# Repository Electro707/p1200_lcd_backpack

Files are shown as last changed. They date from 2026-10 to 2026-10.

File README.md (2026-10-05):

# P1200 - LCB Backpack
# WIP

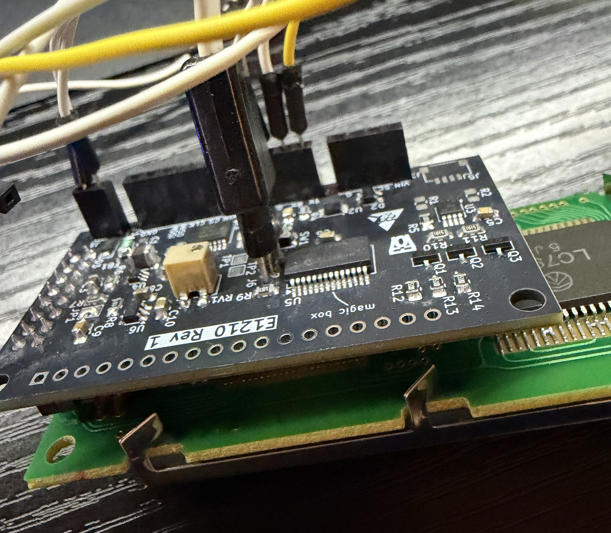
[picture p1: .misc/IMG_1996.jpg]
Image of board on an LCD during development

*Image of board on an LCD during development*

This project is for a generic LCD backpack, similar to the many ones out there, with some distinct features that lead me to build my own:

- Negative voltage for the LCD Bias
    - This was the biggest reason I made this project, as I had an older LCD that wouldn't work unless the LCD is biased to -2v. This is OK as most LCDs can be biased to -9v below VCC, I think?
- Both 5v and 3.3v power and data compatibility
- UART, SPI, and I2C protocols
- The ability to offload some functionality to this backpack, such as animations on the LCD

# Project Structure:

- E1201: The KiCAD PCB files
- F1202: The firmware folder
- Release: All locked in files

# PCB Jumper and Notes

TODO: this section

# PCB Errata
The ERRATA's for the latest revision PCB can be found in [`ERRATA.md`](ERRATA.md)

# Firmware
The [firmware for this project](F1202/) is targeted towards the MCU on board (PIC16F18155).

To use the project, open it up in MPLAB IDE (v6.35 used), with PIC-AS 4.00 (comes with XC8) and device pack `PIC16F1xxxx_DFP==1.31.465` (other version should be OK, noted for repeatability).

The project is written in assembly.
Why? Why not?
This was mostly for my learning of writing an entire firmware in bare assembly and getting familiar with the PIC architecture. I found it fun.

More info on the firmware, including the communication protocol, can be found in [F1202/README.md](F1202/README.md)

# License
This project is licensed under [GPLv3](LICENSE.md)**

** This excludes the files in `E1201/SparkFun-Qwiic.pretty`, as they [came from the Sparkfun](https://www.sparkfun.com/qwiic)

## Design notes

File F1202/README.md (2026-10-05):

# F1202 Detailed Document

This firmware is designed to run on a PIC16F18154 on a E1201 PCBA

## UART Protocol

This firmware speaks over 19200 8N1 serial.

This uses an escape frame sequence, with the escape key (0x1B) serving as the escape code.

Responses are ACK (0x06) for successful command execution, or NACK (0x15) for invalid commands or arguments

The fist byte is the command, which the following are available. Anything with a {N} means it's not implemented yet
- {N}0x01: Get firmware name
- 0x1x: LCD direct commands
    - 0x10: Clear and home
    - 0x11: Go home
    - {N}0x12: Set DRAM position
        - 1 byte argument
    - 0x13: Write to display
        - N byte, continuous
        - An ACK is sent every byte, and directly updates the LCD
    - {N}0x1A: Set CGRAM address
        - 1 byte
    - {N}0x1B: Set CGRAM data
        - 5 bytes
- {N}0x2x: Backlight commands
    - 0x20: Turn off backlight
    - 0x21: Turn on regular backlight
    - 0x22: Turn on RGB backlight
    - 0x23: Set regular (R) backlight PWM
        - 1 byte argument
    - 0x24: Set G backlight PWM
        - 1 byte argument
    - 0x25: Set B backlight PWM
        - 1 byte argument

## SPI Protocol

TODO

## I2C Protocol

TODO

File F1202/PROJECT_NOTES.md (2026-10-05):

# F1202 Notes

> These are notes I wrote down when developing the firmware. Some of them may be handy, some not ¯\_(ツ)_/¯

Each cycle in our system is 250nS (16 Mhz / 4)

according to hd444780:
- the data setup time 80nS, so 1 cycle is ok.
- PWEH is 230nS, so best to have another NOP if we are running back-to-back commands with no data change, but shouldn't be needed
- Setup time is 60nS, so more than enough for 1 cycle

We are using the busy pin, so that is the waiting mechanism in our system.

When writing data, there is a 4uS delay on top of the BUSY pin going LOW due to tADD, so that has to be done manually. Would result in 16 NOPs.

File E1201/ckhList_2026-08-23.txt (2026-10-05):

Unknown List

Schematic Part#: E1201 Rev 1
PCB Part#: 
Reviewers: JB
Date: 2026-08-23
Notes:

Schematic, Generic: 
- [ X ] Run ERC, ensure all errors are accounted for (s1)
- [ X ] Ensure title block is somewhat correct (s2)
- [ X ] Ensure a nominal passive voltage/power/tolerances spec are listed (s3)
- [N/A] Check that all passives with non-nominal rating (especially capacitor voltage) is explicitly called out (s4)
- [ X ] Check pinout of any previously unused symbol against datasheet (s5)
- [ X ] Ensure footprint of symbols are set to maximal pad size if pcb space allows for hand-solderability (s6)
- [ X ] Inverted signals should be indicated (bar on top or _N suffix) (s7)

Schematic, Digital: 
- [ X ] Check that a microcontroller's pin functions is allowed on that pin, either fixed function per pin or an internal mux (sdig1)
        > mcu has pps, check all IO ports required can be connected
- [ X ] Double check I2C and SPI connections (SDA vs SCL for example) (sdig2)
- [ X ] Triple check UART directionality, or add poka-yoke (sdig3)

PCB, Generic: 
- [ X ] Check design rule check matches manufacturer tolerances, if different than default (p1)
- [ X ] Run DRC, ensure no unexpected errors (p2)
- [ X ] Ensure copper pours have no neck-downs (p3)
- [ X ] Ensure copper pours are tied to a net (p4)
- [ X ] Check footprint (especially self-made) of any previously unused footprint against datasheet (p5)

PCB, Silkscreen: 
- [ X ] Check that reference designators are close to their component (ps1)
- [ X ] Check for pcb part number and revision on silkscreen (ps2)
- [ X ] Check that silkscreen text is visible and not obscured by components in 3D viewer, if possible (ps3)
- [ X ] Check that silkscreen on bottom side of the board are inverted (ps4)
- [ X ] (optional) Add easter eggs (ps5)

PCB, Mechanical: 
- [N/A] Check that the board with components fits inside the enclosure, including mounting hole size (if already designed or fixed) (pm1)
- [ X ] Check for screw head clearance, and mark outline in silkscreen if room allows (pm2)

PCB, High Voltage: 
- [N/A] Ensure adequate clearance and creepage around high voltage traces (phv1)
- [N/A] For any area of the board with >50v, add a high voltage warning on the silkscreen (phv2)

PCB, Feedback Resistors: 
- [N/A] Check that high impedance paths, such as those feedback resistors in an op-amp circuit, are close to the component (pf1)

Gerbers: 
- [ X ] Quickly go through generated gerber files and individually check each layer (g1)

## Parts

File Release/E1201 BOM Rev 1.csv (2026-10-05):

Reference | Qty | DNP | Part Number | Description | Value
C1 | 1 |  |  | Capacitor, 100pF, 0805 | 100pF
C2,C4,C5,C6 | 4 |  |  | Capacitor, 100nF, 0805 | 100nF
C3,C7 | 2 |  |  | Capacitor, 10uF, 0805 | 10uF
C8,C10 | 2 |  |  | Capacitor, 2.2uF, 0805 | 2.2uF
C9 | 1 |  |  | Capacitor, 1uF, 0805 | 1uF
D1,D2 | 2 |  | ESDA14V2SC5 | Quad TVS Diode Array, 14.2V Standoff, 4 Channels, 400W, ±30kV, SOT-23-5
D3 | 1 |  | SMF5V0A | 200W unidirectional Transil Transient Voltage Suppressor, 5Vrwm, SMF
F1 | 1 |  | 0ZCJ0050FF2G | Polyfuse, 500mA, 1206 | 500mA
FB1 | 1 |  | BLM21AG102SN1D | Ferrite bead, 0805 | FerriteBead
J1 | 1 |  |  | Header, 0.1”, 1x2, Right Angle | Screw_Terminal_01x02
J2,J3 | 2 |  |  | Header, 0.1”, 1x4, Right Angle | Conn_01x04_Socket
J4 | 1 |  |  | Header, 0.1”, 1x6, Right Angle | Conn_01x06_Socket
J5 | 1 |  | SM04B-SRSS-TB |  | QWIIC
J7 | 1 |  |  | Header, 0.1”, 2x8, Right Angle | Conn_02x08_Odd_Even
J8 | 1 |  |  | Header, 0.1”, 1x18, Right Angle | Conn_01x18
L1 | 1 |  | CBC3225T4R7MR | Inductor, 1210 | 4.7uH
Q1,Q2,Q3 | 3 |  | MMBF170 | MOSFET, 0.5A Id, 60V Vds, N-Channel, SOT-23
R1,R2 | 2 | DNP |  | Resistor, 5.1k, 1%, 0805 | 5.1k
R3,R4,R5,R8,R9 | 5 |  |  | Resistor, 10k, 1%, 0805 | 10k
R6 | 1 |  |  | Resistor, 20k, 1%, 0805 | 20k
R7 | 1 |  |  | Resistor, 180k, 1%, 0805 | 180k
R10,R11 | 2 |  |  | Resistor, 5.1k, 1%, 0805 | 5.1k
R12,R13,R14 | 3 |  |  | Resistor, 510 Ohm, 1%, 0805 | 510
RV1 | 1 |  | 3214X-1-103E | Potentiometer, 10k, Vertical, SMD | 10k
SW1 | 1 |  | KMR211G LFS | Switch, SPST, SMD | SW_Push
U1 | 1 |  | TXU0304PW | 4-Bit Bidirectional Voltage-Level Translator, Fixed Direction, 1.08 - 5.5V , TSSOP-14
U2 | 1 |  | TXU0202DCU | 2-Bit Unidirectional Voltage-Level Translator Fixed Direction , VSSOP-8
U3 | 1 |  | TCA9517ADGK | Level-Translating I2C Bus Buffer/Repeater, VSSOP-8
U4 | 1 |  | TPS61222DCK | 400 mA Step-Up Converter, Fixed 5V Output Voltage, 0.7-5.5V Input Voltage, SC-70
U5 | 1 |  | PIC16F18154-xSS PIC16F18155-xSS | IC, Microcontroller, 7KW FLASH, 512B SRAM, SSOP-28
U6 | 1 |  | LM2776 | IC, Switched capacitor inverter, +2.7 to +5.5V to negative, 200mA, SOT-23-6

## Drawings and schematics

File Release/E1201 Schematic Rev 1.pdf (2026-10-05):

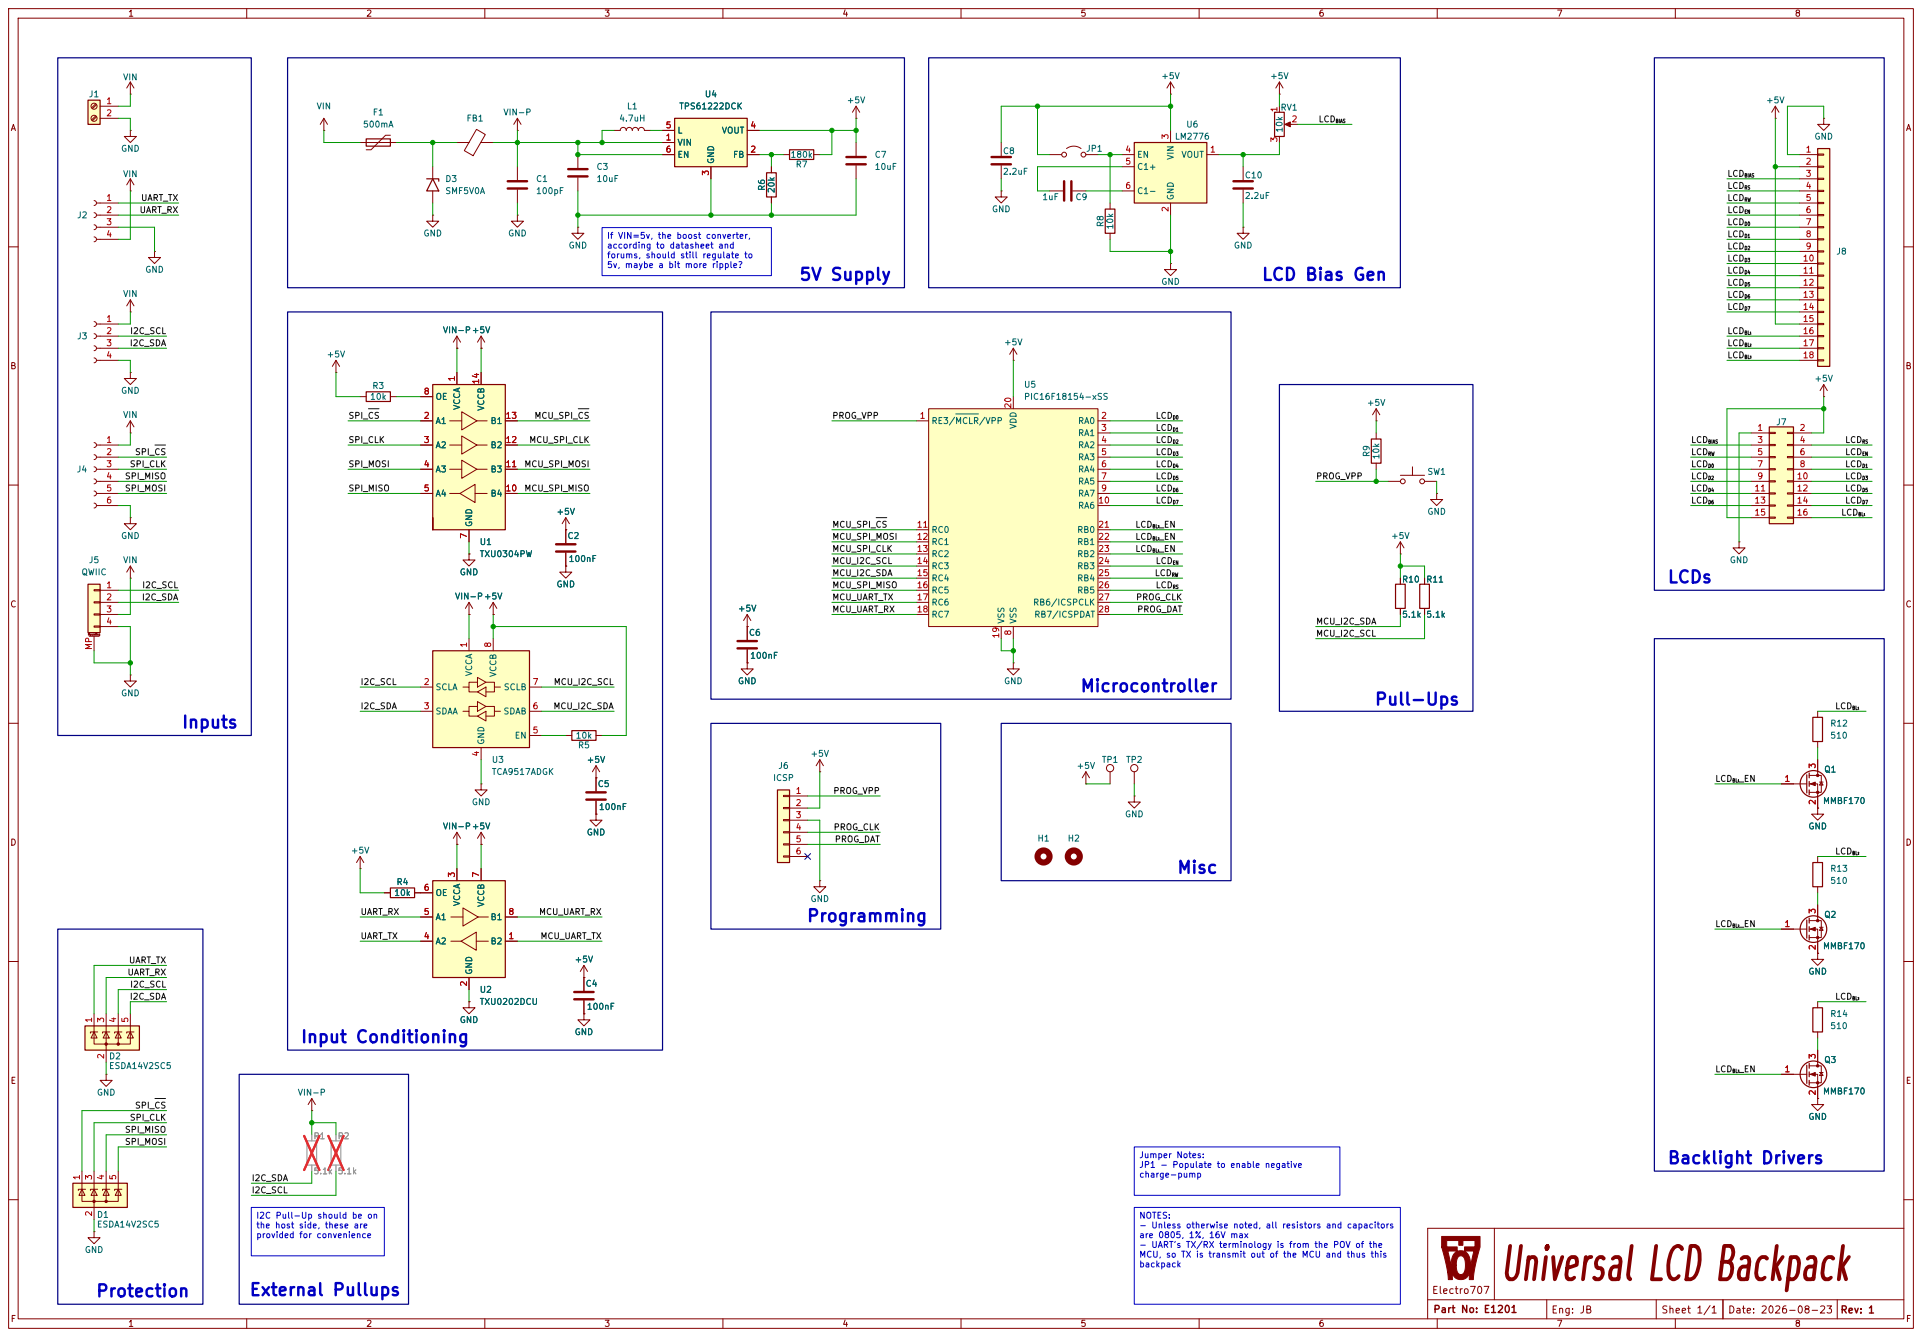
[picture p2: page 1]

If VIN=5v, the boost converter,
according to datasheet and
forums, should still regulate to 5v, maybe a bit more ripple?

8 RA7 9 RA6 10 RC0 11 RC1 12 RC2 13 RC3 14 RC4 15 RC5 16 RC6 17 RC7 18 VDD 20 RB0 21 RB1 22 RB2 23 RB3 24 RB4 25 RB5 26 RB6/ICSPCLK 27 RB7/ICSPDAT 28 VSS 19 U5PIC16F18154-xSS GND

Jumper Notes: JP1 - Populate to enable negative

I2C Pull-Up should be on

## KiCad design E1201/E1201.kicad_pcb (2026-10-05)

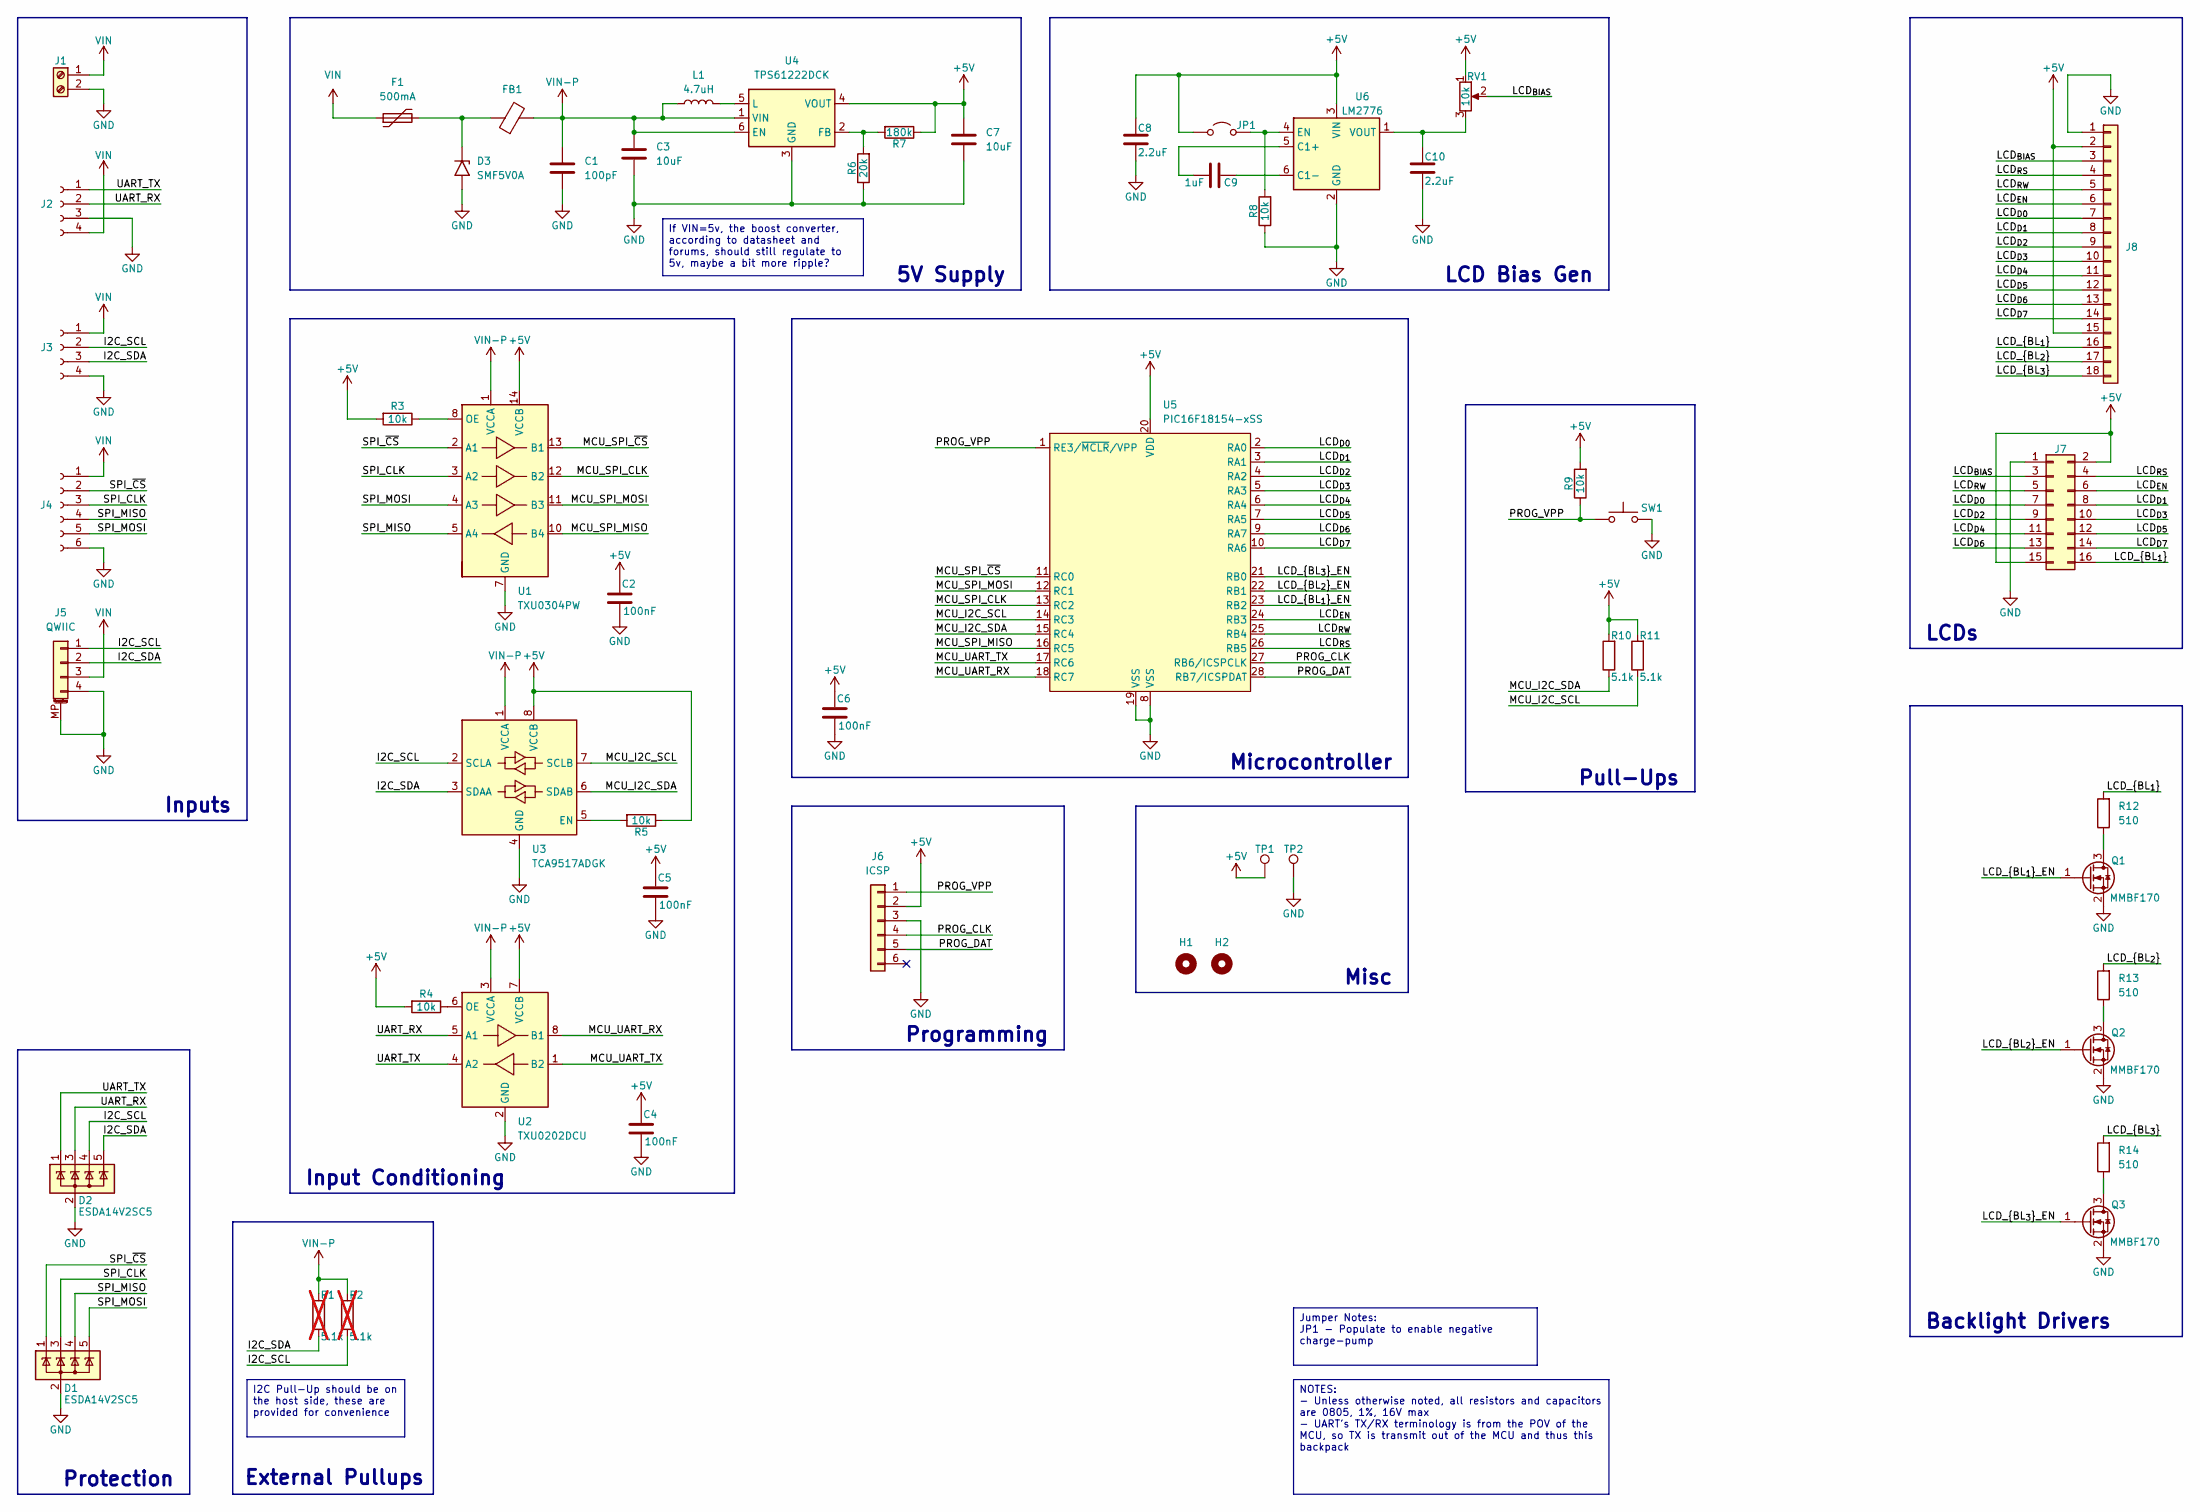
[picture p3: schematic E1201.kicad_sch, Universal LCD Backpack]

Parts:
C1: 100pF; C_0805_2012Metric_Pad1.18x1.45mm_HandSolder
C2, C4, C5, C6: 100nF; C_0805_2012Metric_Pad1.18x1.45mm_HandSolder
C3, C7: 10uF; C_0805_2012Metric_Pad1.18x1.45mm_HandSolder
C8, C10: 2.2uF; C_0805_2012Metric_Pad1.18x1.45mm_HandSolder
C9: 1uF; C_0805_2012Metric_Pad1.18x1.45mm_HandSolder
D1, D2: ESDA14V2SC5; SOT-23-5
D3: SMF5V0A; D_SMF
F1: 500mA; Fuse_1206_3216Metric_Pad1.42x1.75mm_HandSolder
FB1: FerriteBead; L_0805_2012Metric_Pad1.05x1.20mm_HandSolder
H1, H2: MountingHole; MountingHole_3.2mm_M3
J1: Screw_Terminal_01x02; PinSocket_1x02_P2.54mm_Vertical
J2, J3: Conn_01x04_Socket; PinSocket_1x04_P2.54mm_Vertical
J4: Conn_01x06_Socket; PinSocket_1x06_P2.54mm_Vertical
J5: QWIIC; JST_SH_SM04B-SRSS-TB_1x04-1MP_P1.00mm_Horizontal
J6: ICSP; Tag-Connect_TC2030-IDC-NL_2x03_P1.27mm_Vertical
J7: Conn_02x08_Odd_Even; PinHeader_2x08_P2.54mm_Vertical
J8: Conn_01x18; PinSocket_1x18_P2.54mm_Vertical
JP1: Jumper_2_Open; SolderJumper-2_P1.3mm_Open_TrianglePad1.0x1.5mm
L1: 4.7uH; L_1210_3225Metric; Part Number CBC3225T4R7MR
Q1, Q2, Q3: MMBF170; SOT-23
R1, R2: 5.1k; R_0805_2012Metric_Pad1.20x1.40mm_HandSolder; not fitted
R3, R4, R5, R8, R9: 10k; R_0805_2012Metric_Pad1.20x1.40mm_HandSolder
R6: 20k; R_0805_2012Metric_Pad1.20x1.40mm_HandSolder
R7: 180k; R_0805_2012Metric_Pad1.20x1.40mm_HandSolder
R10, R11: 5.1k; R_0805_2012Metric_Pad1.20x1.40mm_HandSolder
R12, R13, R14: 510; R_0805_2012Metric_Pad1.20x1.40mm_HandSolder
RV1: 10k; Potentiometer_Bourns_3214X_Vertical
SW1: SW_Push; SW_Push_1P1T_NO_CK_KMR2
TP1, TP2: TestPoint; TestPoint_Pad_1.5x1.5mm
U1: TXU0304PW; TSSOP-14_4.4x5mm_P0.65mm
U2: TXU0202DCU; VSSOP-8_2.3x2mm_P0.5mm
U3: TCA9517ADGK; VSSOP-8_3x3mm_P0.65mm
U4: TPS61222DCK; Texas_R-PDSO-G6
U5: PIC16F18154-xSS; SSOP-28_5.3x10.2mm_P0.65mm
U6: LM2776; SOT-23-6

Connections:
+5V: C2.2, C4.2, C5.2, C6.2, C7.2, C8.2, J6.2, J7.2, J7.15, J8.2, J8.15, JP1.1 (A), R3.2, R4.2, R5.1, R7.1, R9.2, R10.2, R11.2, RV1.1, TP1.1 (1_1), U1.14 (VCCB), U2.7 (VCCB), U3.8 (VCCB), U4.4 (VOUT), U5.20 (VDD), U6.3 (VIN)
/I2C_SCL: D2.4 (K), J3.2, J5.1, R2.1, U3.2 (SCLA)
/I2C_SDA: D2.5 (K), J3.3, J5.2, R1.1, U3.3 (SDAA)
/LCD_{BIAS}: J7.3, J8.3, RV1.2
/LCD_{BL_{1}}: J7.16, J8.16, R12.2
/LCD_{BL_{1}}_EN: Q1.1 (G), U5.23 (RB2)
/LCD_{BL_{2}}: J8.17, R13.2
/LCD_{BL_{2}}_EN: Q2.1 (G), U5.22 (RB1)
/LCD_{BL_{3}}: J8.18, R14.2
/LCD_{BL_{3}}_EN: Q3.1 (G), U5.21 (RB0)
/LCD_{D0}: J7.7, J8.7, U5.2 (RA0)
/LCD_{D1}: J7.8, J8.8, U5.3 (RA1)
/LCD_{D2}: J7.9, J8.9, U5.4 (RA2)
/LCD_{D3}: J7.10, J8.10, U5.5 (RA3)
/LCD_{D4}: J7.11, J8.11, U5.6 (RA4)
/LCD_{D5}: J7.12, J8.12, U5.7 (RA5)
/LCD_{D6}: J7.13, J8.13, U5.9 (RA7)
/LCD_{D7}: J7.14, J8.14, U5.10 (RA6)
/LCD_{EN}: J7.6, J8.6, U5.24 (RB3)
/LCD_{RS}: J7.4, J8.4, U5.26 (RB5)
/LCD_{RW}: J7.5, J8.5, U5.25 (RB4)
/MCU_I2C_SCL: R11.1, U3.7 (SCLB), U5.14 (RC3)
/MCU_I2C_SDA: R10.1, U3.6 (SDAB), U5.15 (RC4)
/MCU_SPI_CLK: U1.12 (B2), U5.13 (RC2)
/MCU_SPI_MISO: U1.10 (B4), U5.16 (RC5)
/MCU_SPI_MOSI: U1.11 (B3), U5.12 (RC1)
/MCU_SPI_~CS: U1.13 (B1), U5.11 (RC0)
/MCU_UART_RX: U2.8 (B1), U5.18 (RC7)
/MCU_UART_TX: U2.1 (B2), U5.17 (RC6)
/PROG_CLK: J6.4, U5.27 (RB6/ICSPCLK)
/PROG_DAT: J6.5, U5.28 (RB7/ICSPDAT)
/PROG_VPP: J6.1, R9.1, SW1.2, U5.1 (RE3/~MCLR/VPP)
/SPI_CLK: D1.3 (K), J4.3, U1.3 (A2)
/SPI_MISO: D1.4 (K), J4.4, U1.5 (A4)
/SPI_MOSI: D1.5 (K), J4.5, U1.4 (A3)
/SPI_~CS: D1.1 (K), J4.2, U1.2 (A1)
/UART_RX: D2.3 (K), J2.2, U2.5 (A1)
/UART_TX: D2.1 (K), J2.1, U2.4 (A2)
GND: C1.1, C2.1, C3.1, C4.1, C5.1, C6.1, C7.1, C8.1, C10.1, D1.2 (A), D2.2 (A), D3.2 (A2), J1.2, J2.3, J3.4, J4.6, J5.4, J5.MP (MountPin), J6.3, J7.1, J8.1, Q1.2 (S), Q2.2 (S), Q3.2 (S), R6.1, R8.1, SW1.1, TP2.1 (1_1), U1.7 (GND), U2.2 (GND), U3.4 (GND), U4.3 (GND), U5.8 (VSS), U5.19 (VSS), U6.2 (GND)
unnamed: D3.1 (A1), F1.2, FB1.1
unnamed: JP1.2 (B), R8.2, U6.4 (EN)
unnamed: Q1.3 (D), R12.1
unnamed: Q2.3 (D), R13.1
unnamed: Q3.3 (D), R14.1
unnamed: R3.1, U1.8 (OE)
unnamed: R4.1, U2.6 (OE)
unnamed: R5.2, U3.5 (EN)
unnamed: R6.2, R7.2, U4.2 (FB)
unnamed: L1.2, U4.5 (L)
unnamed: C9.1, U6.5 (C1+)
unnamed: C9.2, U6.6 (C1-)
unnamed: C10.2, RV1.3, U6.1 (VOUT)
VIN: F1.1, J1.1, J2.4, J3.1, J4.1, J5.3
VIN-P: C1.2, C3.2, FB1.2, L1.1, R1.2, R2.2, U1.1 (VCCA), U2.3 (VCCA), U3.1 (VCCA), U4.1 (VIN), U4.6 (EN)

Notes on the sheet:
Input Conditioning
LCD Bias Gen
Pull-Ups
External Pullups
Misc
5V Supply
LCDs
Backlight Drivers
Inputs
Protection
Microcontroller
Programming
If VIN=5v, the boost converter, according to datasheet and forums, should still regulate to 5v, maybe a bit more ripple?
I2C Pull-Up should be on the host side, these are provided for convenience
Jumper Notes: JP1 - Populate to enable negative charge-pump
NOTES: - Unless otherwise noted, all resistors and capacitors are 0805, 1%, 16V max - UART's TX/RX terminology is from the POV of the MCU, so TX is transmit out of the MCU and thus this backpack

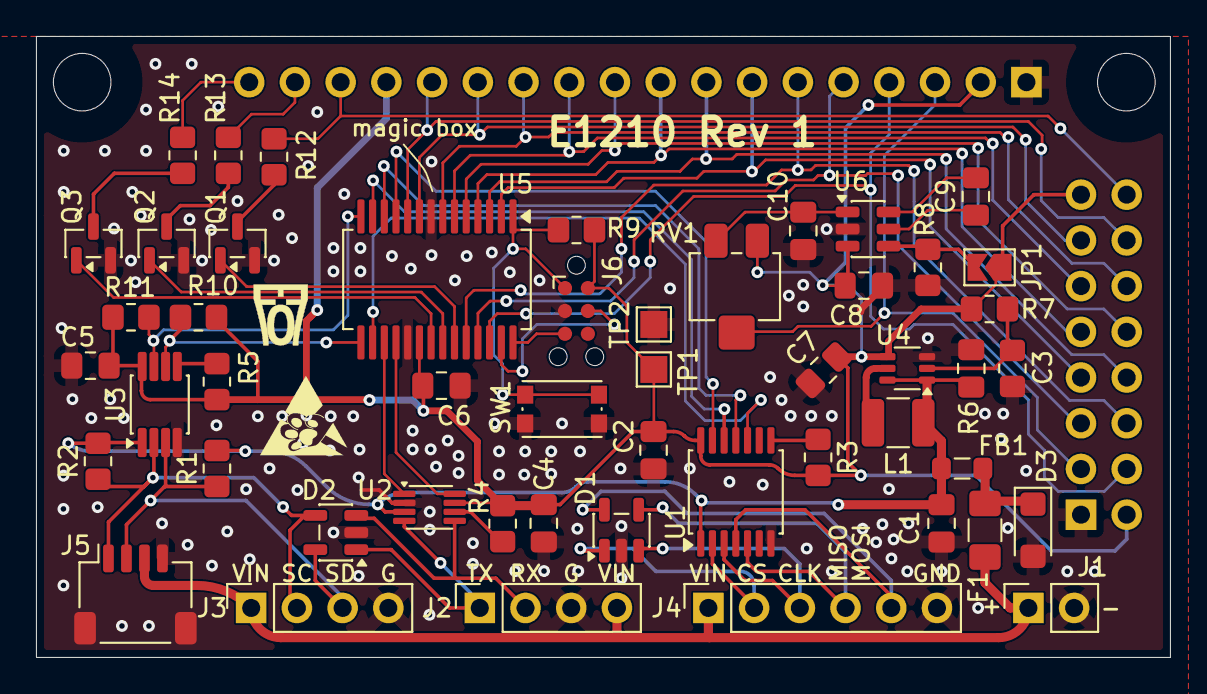
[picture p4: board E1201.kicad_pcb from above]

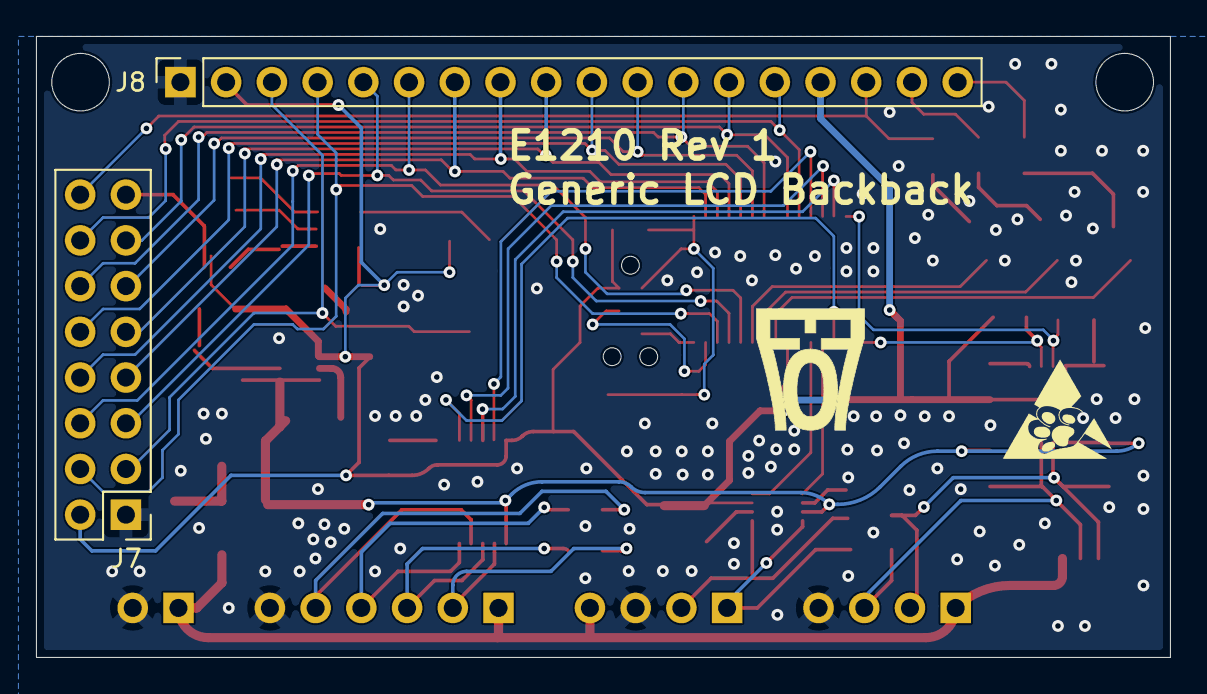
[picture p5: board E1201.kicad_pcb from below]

Board: 2 copper layers, 63.0 x 34.5 mm, 54 parts (2 on the bottom side), 54 nets.

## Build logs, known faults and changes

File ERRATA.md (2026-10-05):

# Errata, Rev 1 PCBA
This section describes any erratas with Rev 1's PCB or PCBA

## E1 - Pin Swapping on LCD
Due to my own version of the symbol for the PIC microcontroller I made, I accidentally swapped pins RA6 and RA7 visually on the schematic, so I wired them flipped

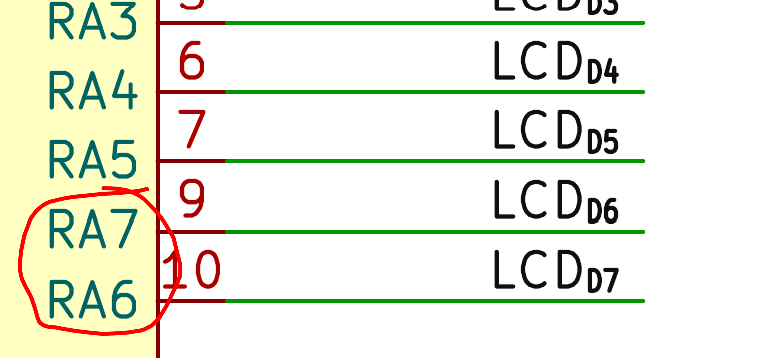
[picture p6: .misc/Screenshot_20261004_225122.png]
Image of schematic


### Fix
Either a painful hardware fix with trace cutting...or a software fix like I implemented in F1202.

## E2 - UART TX No Pullup
On power-on, or MCU restart, the UART "transmits" 0x00 due to the lack of a pull-up on that line and the rising edge when the IOs are initialized.

### Fix
Either deal with the initial 0 on the line when powering on or restarting the firmware, or add a 10k pull-up resistor from TX to VCC

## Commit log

2026-06-13 save point
    [E1201.kicad_pcb, E1201.kicad_sch]
2026-10-05 PCB Commit, this is what I used to order
    [E1201.kicad_pcb, E1201.kicad_sch]
2026-10-05 Added Gerber, schematic, and BOM as-is for Rev 1
    [E1201 BOM Rev 1.csv]
